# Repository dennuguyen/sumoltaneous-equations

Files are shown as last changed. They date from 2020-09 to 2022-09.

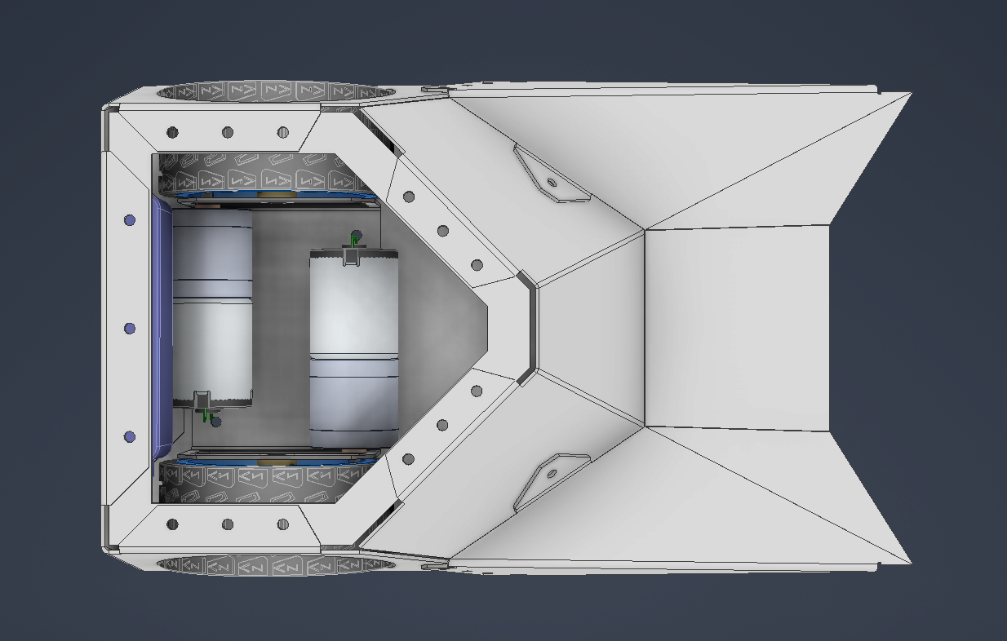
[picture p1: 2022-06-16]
sumoltaneous-equations-inventor-sheet-metal/Assembly top.png

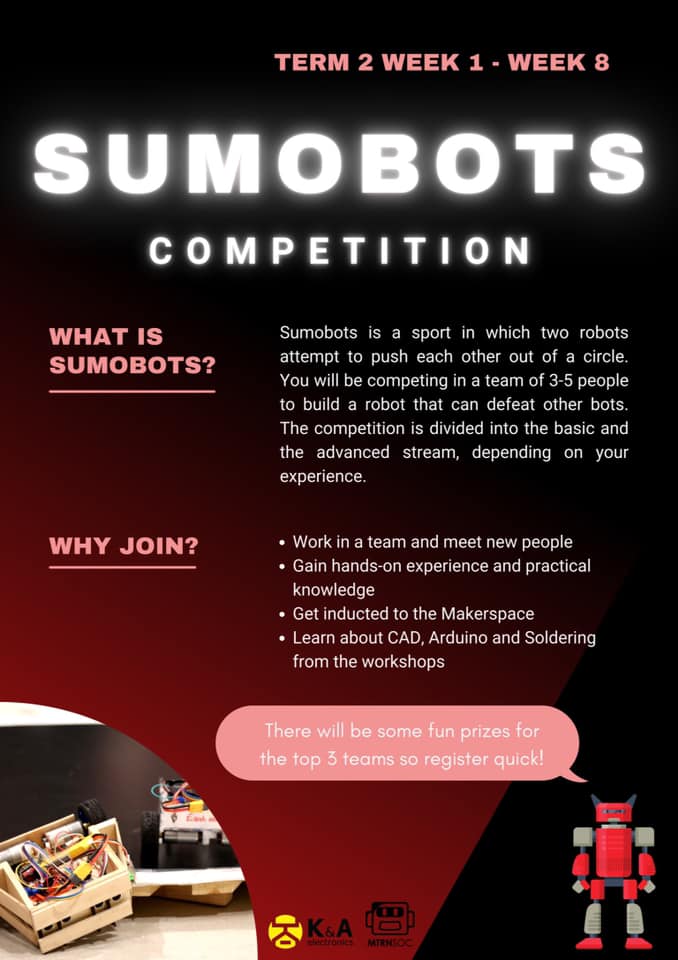
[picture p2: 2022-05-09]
README/sumobots.jpg

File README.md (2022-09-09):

# Sumoltaneous Equations
atement

Build a UGV to win the sumobot competition i.e. to win, it must be the last robot to overstep the boundary of the dohyo. It must also adhere to the rules and use the parts provided by UNSW Create.

## Resources

- Japanese Sumobots Documentary: https://youtu.be/mS-L2fpV1Is
- Sumobot Strategies: https://youtu.be/rthMiqFCiBA
- SENAI-SC Sumo Robot Example: https://blog.jsumo.com/senai-sc-sumo-robot/.
- Impala Sumo Robot Example: https://blog.jsumo.com/impala-sumo-robot/.
- Arduino Nano Datasheet: https://Datasheet.arduino.cc/hardware/nano
- Arduino Nano Pinout: https://www.makerguides.com/wp-content/uploads/2020/10/arduino-nano-pinout.png
- L298N Motor Controller Datasheet: https://components101.com/sites/default/files/component_datasheet/L298N-Motor-Driver-Datasheet.pdf
- HC-SR04 Ultrasonic Sensor Datasheet: https://www.digikey.com/htmldatasheets/production/1979760/0/0/1/hc-sr04.html
- MH-B IR Sensor Datasheet: https://components101.com/sites/default/files/component_datasheet/Datasheet%20of%20IR%20%20Sensor.pdf
- Turnigy 1250 mAh 3S 30C LiPo Battery: https://hobbyking.com/en_us/turnigy-1250mah-3s-30c-lipo-pack-long.html
- JGA25-370 DC Motor: https://www.aliexpress.com/item/1005001279982165.html
- JGA25-370 Bracket: https://www.alibaba.com/product-detail/JGA25-370-Fixed-Support-Gear-Motor_1600120808634.html
- Wheel: https://www.aliexpress.com/item/32870820813.html
- TCRT5000: https://www.vishay.com/docs/83760/tcrt5000.pdf

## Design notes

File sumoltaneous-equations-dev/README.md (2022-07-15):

# Sumoltaneous Equations

## State Diagram

```mermaid
stateDiagram-v2
    state if <<choice>>
    [*] --> if

    if --> PlanEdgeAvoidance: Edge detected
    if --> PlanAttack: Opponent detected
    if --> PlanSearch: Opponent not detected

    state PlanSearch {
        [*] --> SearchTurnRight
        SearchTurnRight: Send turn right command
        SearchTurnRight --> [*]
    }

    state PlanAttack {
        state if_which_distance_sensor <<choice>>
        state join_attack_move <<join>>
        [*] --> if_which_distance_sensor
        if_which_distance_sensor --> TurnLeft: If left distance sensor is triggered
        TurnLeft: Send turn left command
        if_which_distance_sensor --> Forward: If front distance sensor is triggered
        Forward: Send forward command
        if_which_distance_sensor --> TurnRight: If right distance sensor is triggered
        TurnRight: Send turn right command
        TurnLeft --> join_attack_move
        Forward --> join_attack_move
        TurnRight --> join_attack_move
        join_attack_move --> [*]
    }

    state PlanEdgeAvoidance {
        [*] --> AvoidTurnLeft
        AvoidTurnLeft: Send turn left command
        AvoidTurnLeft --> [*]
    }

    PlanSearch --> Move: Send move command
    PlanAttack --> Move: Send move command
    PlanEdgeAvoidance --> Move: Send move command

    state Move {
        state join_after_move <<join>>
        [*] --> DriveModel
        DriveModel
        DriveModel --> LeftMotor: Send motor command
        DriveModel --> RightMotor: Send motor command
        LeftMotor --> join_after_move
        RightMotor --> join_after_move
        join_after_move --> [*]
    }

    Move --> if
```

Move refers to moving the motors at max velocity. There are 3 moves that we can make:
- Turning left.
- Turning right.
- Moving forward.

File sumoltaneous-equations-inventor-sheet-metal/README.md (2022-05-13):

# Sumoltaneous Equations

## Autodesk Inventor Professional 2023

1. Go to https://www.autodesk.com/education/edu-software.
1. Install Autodesk Inventor Professional 2023.

You will need to provide Autodesk proof that you are a student.

## BOM

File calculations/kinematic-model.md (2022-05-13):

# Kinematic Model

kinematic-model

The sumobot's state-space representation will let us localise the robot.

Let the state vector be:
$$
\vec{x}(t) = \left(\begin{matrix} x(t) \\ y(t) \\ \phi(t) \end{matrix}\right)
$$

The change in state over time is:
$$
\frac{d\vec{x}(t)}{dt} = \frac{d}{dt}\left(\begin{matrix} x(t) \\ y(t) \\ \phi(t) \end{matrix} \right)=
    \left(
        \begin{matrix}
            v(t) \cdot \cos\left(\phi(t)\right) \\
            v(t) \cdot \sin\left(\phi(t)\right) \\
            \omega(t) \\
        \end{matrix}
    \right)
$$

- $v$ is the linear velocity in x-y directions.
- $w$ is the angular velocity.

Let the input vector be:
$$
\vec{u}(t) = \left(\begin{matrix} \omega_{L}(t) \\ \omega_{R}(t) \end{matrix}\right)
$$

- $w_{L}$ is the angular veocity for each left wheel.
- $w_{R}$ is the angular veocity for each right wheel.

The left wheels are driven by a single left motor. The right wheels are driven by a single right motor. The kinematic model can be simplified to be a two-wheeled differential where the instantaneous centre of rotation is along the centre-line between the front and rear axes.

The linear velocity is:
$$
v(t) = \frac{R_{wheel}}{2}\left(\omega_{L}(t) + \omega_{R}(t)\right)
$$

The angular velocity is:
$$
\omega(t) = \frac{R_{wheel}}{2L}\left(\omega_{R}(t) - \omega_{L}(t) \right)
$$

The change in states over time is therefore:
$$
\frac{d\vec{x}(t)}{dt} =
    \left(
        \begin{matrix}
            \frac{R_{wheel}}{2}\left(\omega_{L}(t) + \omega_{R}(t)\right) \cdot \cos\left(\phi(t)\right) \\
            \frac{R_{wheel}}{2}\left(\omega_{L}(t) + \omega_{R}(t)\right) \cdot \sin\left(\phi(t)\right) \\
            \frac{R_{wheel}}{2L}\left(\omega_{R}(t) - \omega_{L}(t) \right) \\
        \end{matrix}
    \right)
$$

> Very important to recognise that the frame of reference is the centroid of the four wheels.

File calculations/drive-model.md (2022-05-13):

# Drive Model

## Motor

The motor model is [JGA25-370](https://ae01.alicdn.com/kf/H8264bb5cf6ff431a86f8ef713a801273X.jpg) rated at $6$ V and with a $46$ reduction ratio.

At no load, the motor is rated as:
$$
\begin{aligned}
    \omega_{\text{no load}} &= 130 \text{ RPM} \\
    i_{\text{no load}} &= 0.1 \text{ A}
\end{aligned}
$$

At load, the motor is rated as:
$$
\begin{aligned}
    \tau_{\text{load}} &= 100 \text{ kg/m} \\
    \omega_{\text{load}} &= 100 \text{ RPM} \\
    i_{\text{load}} &= 0.45 \text{ A}
\end{aligned}
$$

At stall, the motor is rated as:
$$
\begin{aligned}
    \tau_{\text{stall}} &= 360 \text{ kg/m} \\
    i_{\text{stall}} &= 1.8 \text{ A}
\end{aligned}
$$

> There is no need to calculate the motor constant because the motor is given to us.

## Gear Train

gear-train

The gear ratio formula between the in and out gear is:
$$
\frac{\omega_{in}}{\omega_{out}} = \frac{n_{in}}{n_{out}} = \frac{d_{out}}{d_{in}} = \frac{\tau_{out}}{\tau_{in}}
$$

Given the dimensional constraints of the gears:
$$
\begin{aligned}
    d_{out} &= 60 \text{ mm} \\
    d_{in} &= 15 \text{ mm} \\
\end{aligned}
$$

With an input torque of $100$ kg/m, the output torque is:
$$
\begin{aligned}
    \frac{d_{out}}{d_{in}} &= \frac{\tau_{out}}{\tau_{in}} \\
    \frac{60}{15} &= \frac{\tau_{out}}{100} \\
    \therefore \tau_{out} &= 400 \text{ kg/m}
\end{aligned}
$$

## Control System

A control system is required to control the torque output of the motor. This is done through observing the supplied current.

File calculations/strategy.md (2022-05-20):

# Strategy

## Mapping

The map is a dohyo i.e. a ring with a black background and white edges.

We know the map will always be sparse. So sparse that it may not be worth the effort to even map it. We just have to make sure we don't risk reaching the edge of the dohyo.

We should only care about where the edge of the ring is and where we are relative to that (this should save A LOT of computation power). How do we do this?

We know:
- The diameter of the ring.
- Our starting position.

If we reach the edge of the dohyo, we can reset our state vector to be at some random point on the edge of the dohyo.

When we track our position, it will be some float coordinates.

## Search Patterns

When searching for the opponent, there are multiple patterns which can be employed:

### Radar

The sumobot just spins on the spot and searches for the opponent.

### Random Search

The sumobot randomly moves to a point on the dohyo and will end its search pattern when it identifies an opponent.

## Path Planning

We know:
- The diameter of the ring.
- Our position within the ring.
- And maybe our opponent's position within the ring too.

This is all the information we need to perform path planning.

There are a few path planning strategies:

### Search And Push (SAP)

An extremely simple strategy.

```mermaid
flowchart LR
    search[Search for Opponent] -->|If target acquired| push[Push Opponent]
    push -->|If lost target| search
```

### Search And Push* (SAP*)

An improved strategy on SAP which considers localisation.

```mermaid
flowchart LR
    search[Search for Opponent] -->|If target acquired| localise_opp[Localise Opponent]
    localise_opp --> plan_path[Plan Path]
    plan_path --> push[Execute Path Step] -->|To update data| search
```

The path planning can be complex e.g.
- We may only want to push the opponent from the inside of the sumobot.
- We may only want to push the opponent from its side or behind and not head on.

The path planning algorithm could be implemented with:
- Queuing waypoints.

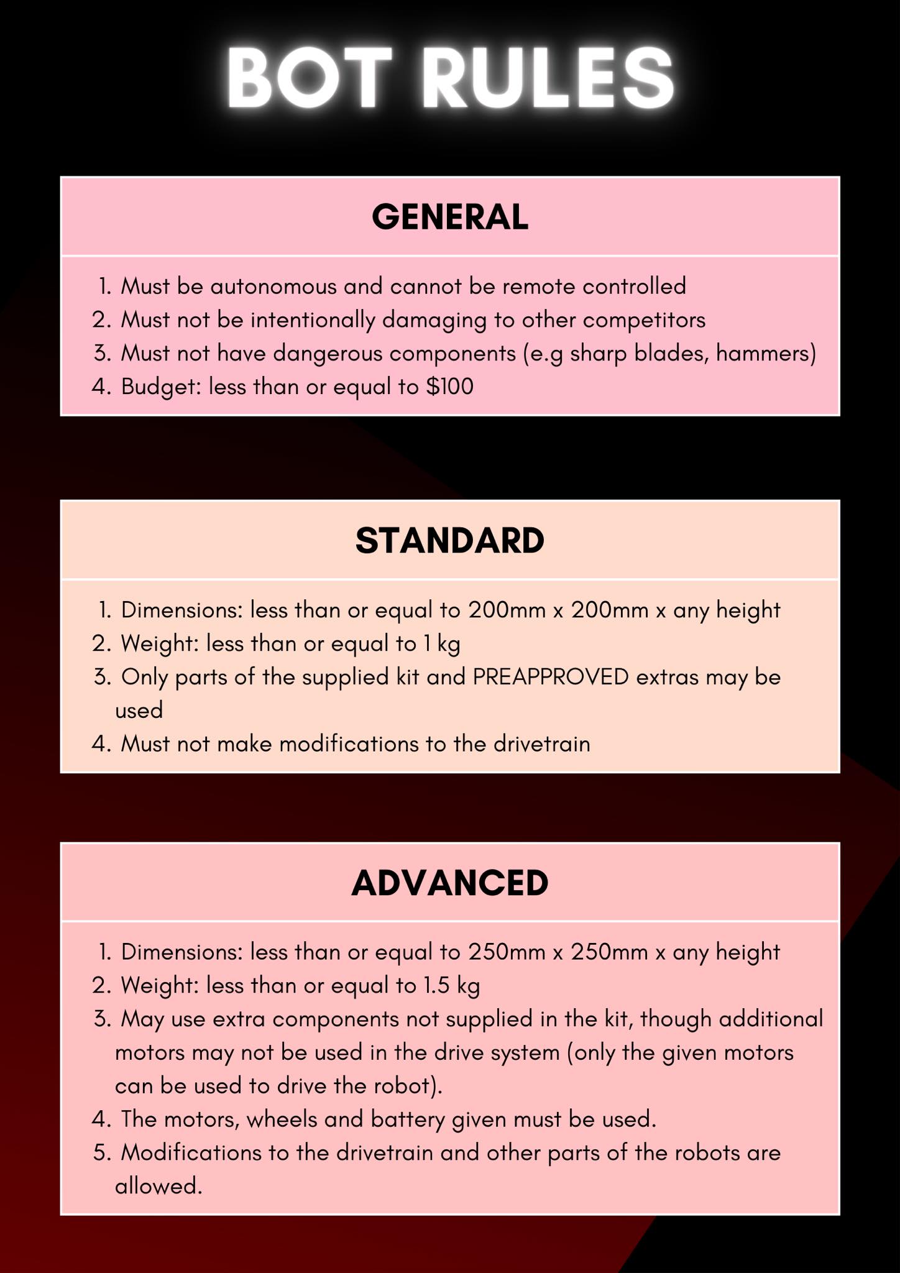
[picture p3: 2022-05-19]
README/bot-rules.jpg

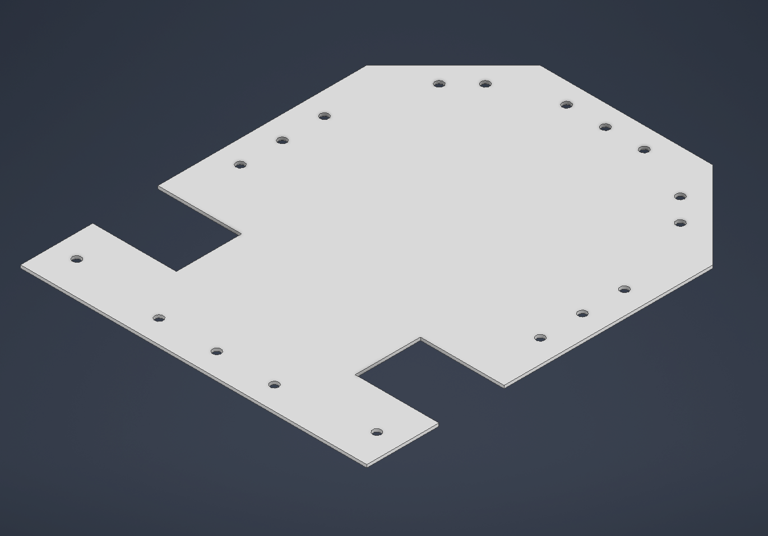
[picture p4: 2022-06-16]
sumoltaneous-equations-inventor-sheet-metal/Bottom.png

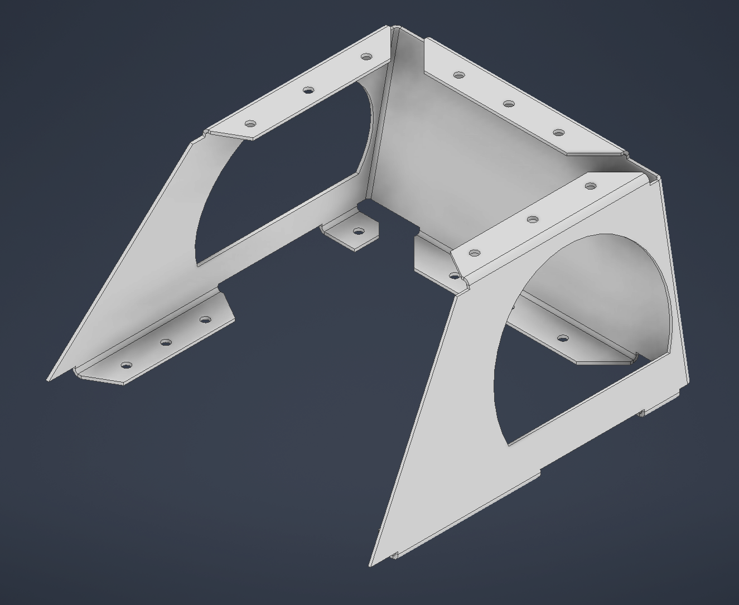
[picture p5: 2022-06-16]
sumoltaneous-equations-inventor-sheet-metal/Back.png

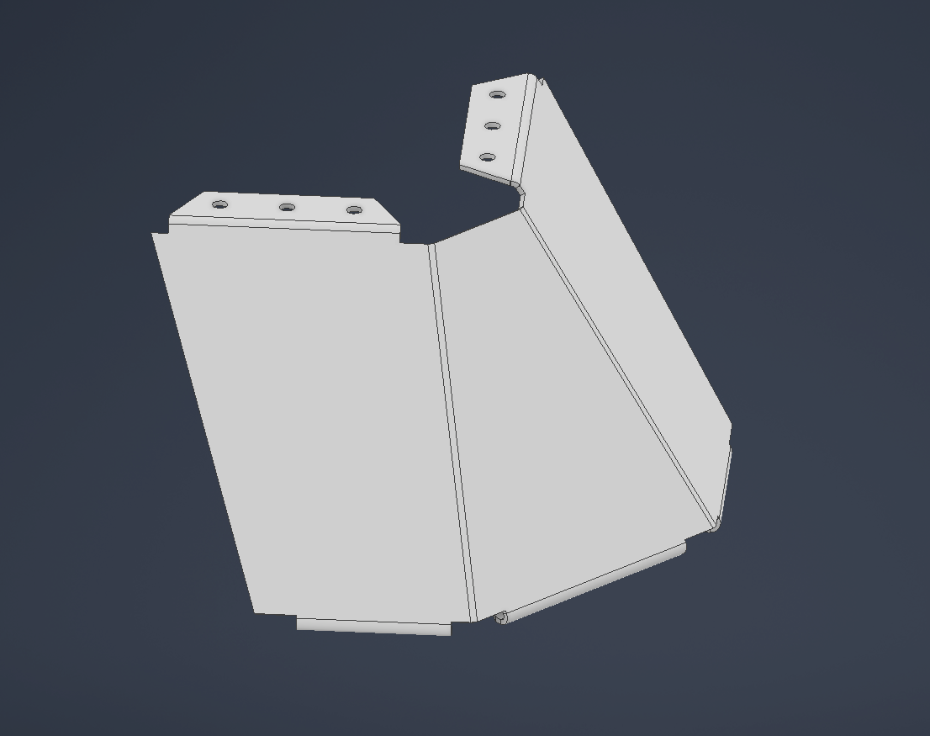
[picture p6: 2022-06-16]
sumoltaneous-equations-inventor-sheet-metal/Front.png

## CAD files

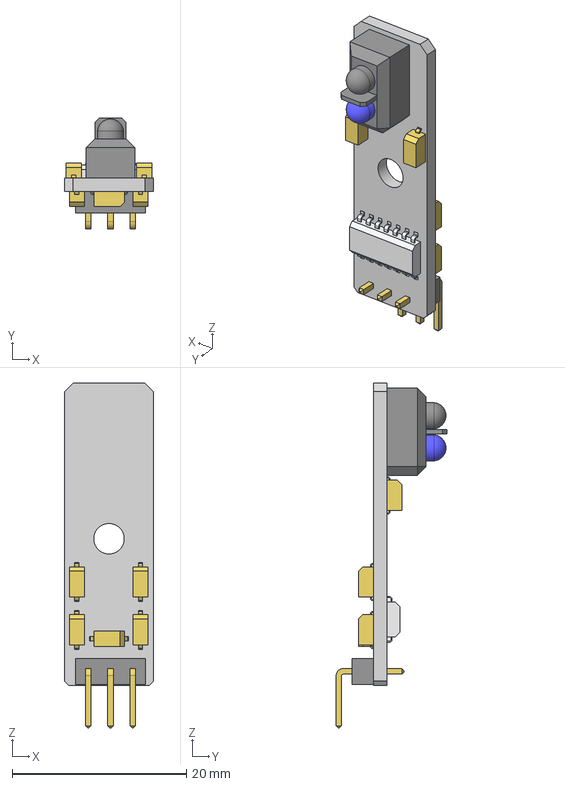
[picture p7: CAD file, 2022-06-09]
sumoltaneous-equations-inventor-sheet-metal/TCRT5000.step
10.2 x 12.7 x 39.6 mm
Line Sensor_1
TCR5000
14 Pin SMT
3 Pin Header 90 Degree line
Cap1 SMT x 7

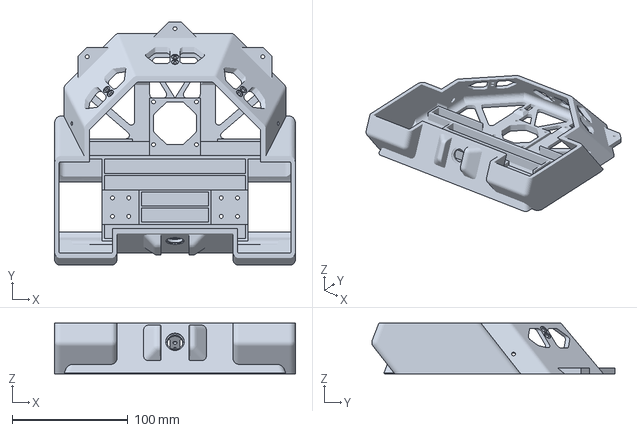
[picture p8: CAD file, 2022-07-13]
sumoltaneous-equations-inventor/v3.3mf
208.0 x 210.1 x 44.0 mm

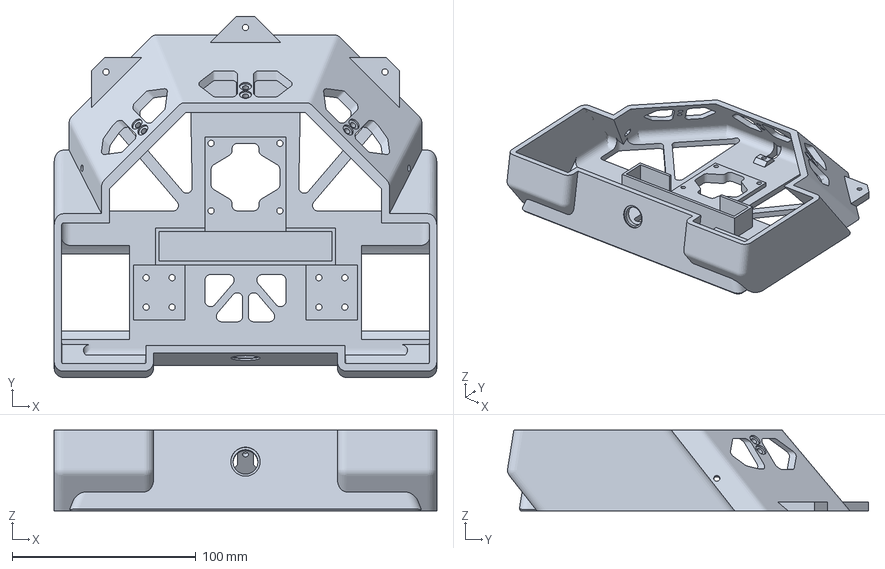
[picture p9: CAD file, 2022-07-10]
sumoltaneous-equations-inventor/AI3MSPRO_Body.3mf
208.0 x 196.2 x 44.0 mm

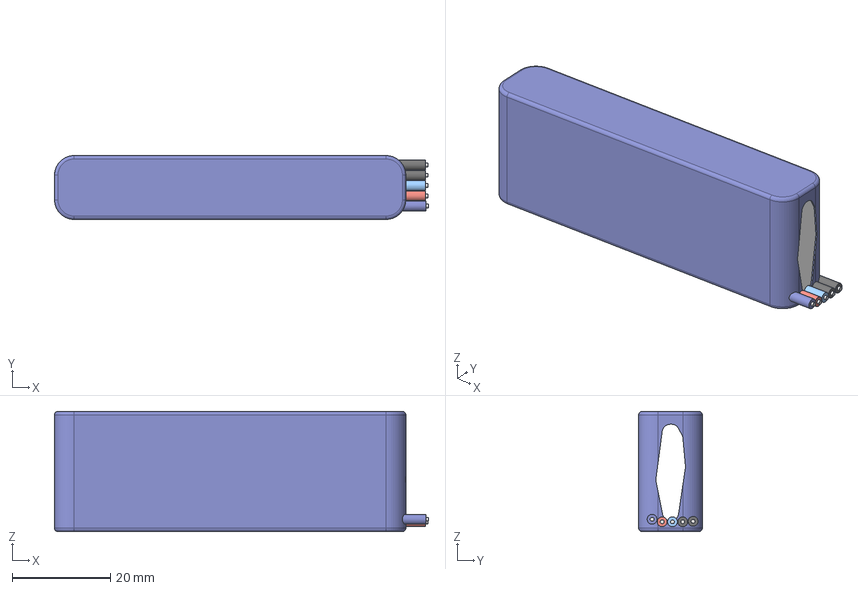
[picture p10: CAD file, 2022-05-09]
sumoltaneous-equations-inventor-sheet-metal/turnigy-lipo-battery.step
76.2 x 13.0 x 24.5 mm

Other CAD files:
sumoltaneous-equations-inventor-sheet-metal/spur-gear-1m-15t.step
sumoltaneous-equations-inventor/v2.3mf
sumoltaneous-equations-inventor-sheet-metal/Backp.ipt
sumoltaneous-equations-inventor-sheet-metal/Bottomp.ipt
sumoltaneous-equations-inventor-sheet-metal/Frontp.ipt
sumoltaneous-equations-inventor-sheet-metal/JGA25-370-bracket-standoff.ipt
sumoltaneous-equations-inventor-sheet-metal/JGA25-370-bracket.ipt
sumoltaneous-equations-inventor-sheet-metal/JGA25-370.ipt
sumoltaneous-equations-inventor-sheet-metal/Motor-bracket.ipt
sumoltaneous-equations-inventor-sheet-metal/Motor-mountp.ipt
sumoltaneous-equations-inventor-sheet-metal/Rampp.ipt
sumoltaneous-equations-inventor-sheet-metal/Spacer.ipt
sumoltaneous-equations-inventor-sheet-metal/Topp.ipt
sumoltaneous-equations-inventor-sheet-metal/body-shape.ipt
sumoltaneous-equations-inventor-sheet-metal/hc-sr04-bracket.ipt
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

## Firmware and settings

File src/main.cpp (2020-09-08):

#include <Arduino.h>

struct Pin {
   public:
    Pin(int pno) : pno(pno), val(LOW) {}

   public:
    int pno;  // pin number
    int val;  // pin value
};

class Wheel {
   public:
    Wheel(int in1, int in2) : in1(Pin(in1)), in2(Pin(in2)) {}
    void init(void) {
        pinMode(in1.pno, OUTPUT);
        pinMode(in2.pno, OUTPUT);
    }
    void forward(void) {
        in1.val = HIGH;
        in2.val = LOW;
    }
    void backward(void) {
        in1.val = LOW;
        in2.val = HIGH;
    }
    void brake(void) {
        in1.val = LOW;
        in2.val = LOW;
    }

   public:
    Pin in1;
    Pin in2;
};

class Sonar {
   public:
    Sonar(int echo, int trig) : echo(echo), trig(trig) {}
    void init(void) {
        pinMode(echo.pno, INPUT);
        pinMode(trig.pno, OUTPUT);
    }
    void clear(void) {
        digitalWrite(trig.pno, LOW);
    }
    void send(void) {
        digitalWrite(trig.pno, HIGH);
    }
    double receive(void) {
        return pulseIn(echo.pno, HIGH) * 0.034 / 2;  // distance in cm
    }

   public:
    Pin echo;
    Pin trig;
};

class Infrared {
   private:
    enum colours {
        MIN = 0,
        BLACK = 900,
        MAX = 1023,
    };

   public:
    Infrared(int sig) : sig(sig) {}
    void init(void) {
        pinMode(sig.pno, INPUT);
    }
    bool edge(void) {
        return analogRead(sig.pno) > BLACK;
    }

   private:
    Pin sig;
};

class Bot {
   private:
    enum wheels {
        LF,  // left front
        RF,  // right front
        LB,  // left back
        RB,  // right back
    };
    enum sensors {
        FRONT,
        LEFT,
        RIGHT,
        BACK,
    };

   public:
    Bot(Wheel (&wheel)[4], Infrared (&gnd)[4], Sonar (&opp)[4])
        : wheel(wheel), gnd(gnd), opp(opp) { init(); }
    void init(void) {
        for (int i = 0; i < 4; i++) {
            wheel[i].init();
            gnd[i].init();
            opp[i].init();
        }
    }
    void forward(void) {
        wheel[LF].forward();
        wheel[RF].forward();
        wheel[LB].forward();
        wheel[RB].forward();
    }
    void backward(void) {
        wheel[LF].backward();
        wheel[RF].backward();
        wheel[LB].backward();
        wheel[RB].backward();
    }
    void brake(void) {
        wheel[LF].brake();
        wheel[RF].brake();
        wheel[LB].brake();
        wheel[RB].brake();
    }
    void left(void) {
        wheel[LF].backward();
        wheel[RF].forward();
        wheel[LB].backward();
        wheel[RB].forward();
    }
    void right(void) {
        wheel[LF].forward();
        wheel[RF].backward();
        wheel[LB].forward();
        wheel[RB].backward();
    }
    void write(void) {
        for (int i = 0; i < 4; i++) {
            digitalWrite(wheel[i].in1.pno, wheel[i].in1.val);
            digitalWrite(wheel[i].in2.pno, wheel[i].in2.val);
        }
    }

   private:
    Wheel (&wheel)[4];
    Infrared (&gnd)[4];  // Infrared sensor detects boundary
    Sonar (&opp)[4];     // Sonar detects opponent
};

int main(void) {
    Wheel wheel[4] = {Wheel(PD0, PD1), Wheel(PD2, PD3), Wheel(PD4, PD5), Wheel(PD6, PD7)};
    Infrared gnd[4] = {Infrared(A0), Infrared(A1), Infrared(A2), Infrared(A3)};
    Sonar opp[4] = {Sonar(PD1, PD2), Sonar(PD1, PD2), Sonar(PD3, PD4), Sonar(PD5, PD6)};
    Bot b(wheel, gnd, opp);

    Serial.begin(9600);

    while (1) {
        // Check edges
        for (int i = 0; i < 4; i++)
            ;

        // Write-out pins.
        b.write();
        delay(50);
    }

    return EXIT_SUCCESS;
}

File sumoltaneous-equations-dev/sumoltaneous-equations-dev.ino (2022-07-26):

#include <Arduino.h>

#include "DistanceSensor.hpp"
#include "Drive.hpp"
#include "EdgeAvoidance.hpp"
#include "IRSensor.hpp"
#include "Motor.hpp"
#include "ToggleButton.hpp"

Motor left_motor(10, A2, A3);
Motor right_motor(11, A0, A1);
Drive drive_model(left_motor, right_motor, 65, 160);

DistanceSensor left_distance_sensor(2, 3);
DistanceSensor front_distance_sensor(4, 5);
DistanceSensor right_distance_sensor(7, 6);

IRSensor left_ir_sensor(8);
// IRSensor right_ir_sensor(9);
// EdgeAvoidance edge_avoidance(left_ir_sensor, right_ir_sensor);

ToggleButton button(12);

void setup() {
    Serial.begin(9600);
    button.await(true);
    delay(5000);
}

void loop() {
    if (left_ir_sensor.read()) {
        drive_model.reverse();
        delay(200);
    } else if (front_distance_sensor.echo() < 800) {
        drive_model.forward();
    } else if (left_distance_sensor.echo() < 800) {
        drive_model.turn_left();
    } else if (right_distance_sensor.echo() < 800) {
        drive_model.turn_right();
    } else {
        drive_model.turn_left();
    }

    if (button.read() == false) {
        drive_model.stop();
        button.await(true);
        delay(5000);
    }
}

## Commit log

2020-09-07 Add getting battery requirement step
2020-09-08 Add sensor classes
2020-09-08 Clarify enum wheels
2020-09-09 Perform motor-battery calculations
2020-09-09 Perform some basic torque calculation
2020-09-09 Ask motor driver questions
2020-12-04 Reorganise directory
    [ARDUINO NANO.SLDPRT, BALLAST.SLDPRT, CHASSIS.3MF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]
2022-04-30 Update power supply in WBS.
2022-04-30 Restructure repository.
    [ARDUINO NANO.SLDPRT, BALLAST.SLDPRT, CHASSIS.3MF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]
2022-05-09 Add battery spec.
2022-05-09 Rename IR sensor.
2022-05-09 Source COTS.
    [ARDUINO NANO.SLDPRT, BALLAST.SLDPRT, CHASSIS.3MF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]
2022-05-09 Find motor model.
2022-05-09 Find wheel.
2022-05-09 Create sheet metal concept.
    [floor.ipt, ramp.ipt]
2022-05-09 Create pyramid for sheet metal concept.
    [chassis.ipt, floor.ipt, ramp.ipt]
2022-05-09 Finalise sheet metal concept.
    [chassis.ipt, ramp.ipt, side.ipt]
2022-05-09 Rename side to panel. Import wheel and motor.
    [JGA25-370.ipt, JGA25-370.step, chassis.ipt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]
2022-05-10 Add motor bracket.
    [JGA25-370-bracket.ipt, JGA25-370-bracket.step]
2022-05-10 Create wheel subasm.
    [JGA25-370-bracket.ipt, ramp.ipt]
2022-05-10 Put wheel subasm in chassis.
    [JGA25-370-bracket-standoff.ipt, chassis.ipt]
2022-05-13 Prep kinematic model.
2022-05-13 Do gear train calcs.
    [gear-train-sketch.ipt]
2022-05-13 Update gear dimensions.
    [gear-train-sketch.ipt]
2022-05-13 Design motor cage.
    [chassis.ipt, motor-cage.ipt]
2022-05-13 Draw kinematic model diagram.
    [motor-cage.ipt]
2022-05-13 Add BOM section.
2022-05-13 Iterate on motor cage.
    [motor-cage.ipt]
2022-05-13 Mate motors with motor cage.
2022-05-14 Draft gear train.
    [JGA25-370-bracket.step, JGA25-370.step, chassis.ipt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]
2022-05-16 Add IMU.
2022-05-17 Initial commit.
    [sumoltaneous_equations.kicad_pcb, sumoltaneous_equations.kicad_sch]
2022-05-19 Sketch HC-SR04 placement.
    [hc-sr04-sensor-placement-sketch.ipt]
2022-05-19 Create ultrasonic sensor mount.
    [chassis.ipt, hc-sr04-bracket.ipt, panel.ipt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]
2022-05-30 final body shape
    [Backp.ipt, Bottomp.ipt, Final-ass.iam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]
2022-05-31 Ramp done
    [Backp.ipt, Bottomp.ipt, Final-ass.iam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]
2022-06-01 Fixed parametric definitions
    [body-shape.ipt]
2022-06-02 Final alignment
    [Backp.ipt, Bottomp.ipt, Final-ass.iam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]
2022-06-03 Added motor mount
    [Backp.ipt, Bottomp.ipt, Final-ass.iam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]
2022-06-03 Fixed assembly
    [Backp.ipt, Bottomp.ipt, Frontp.ipt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]
2022-06-06 Added ultrasonic sensor windows
    [body-shape.ipt]
2022-06-09 Update sensor model.
    [MH-B-ir-sensor.step, TCRT5000.step]
2022-06-16 Final assembly (hopefully)
    [Backp.ipt, Bottomp.ipt, Frontp.ipt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]
2022-06-16 Add mounting hole for L298N.
    [body-shape.ipt]
2022-06-22 Move old revision.
    [Backp.ipt, Bottomp.ipt, Frontp.ipt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]
2022-06-22 Hollow chassis
    [chassis.ipt]
2022-06-22 Hollow chassis with FEA
    [chassis.ipt]
2022-06-22 Add mounting hole for JGA25-370.
    [chassis.ipt]
2022-06-23 Get bracket from old version.
    [JGA25-370-bracket.ipt, JGA25-370-mount.ipt]
2022-06-23 making ramp mounts
    [chassis.ipt]
2022-06-23 Add COTS and create wheel sub asm.
    [JGA25-370.ipt, TCRT5000.step, turnigy-lipo-battery.step]
2022-06-23 Finalise motor mounting hole sketch.
    [chassis.ipt]
2022-06-23 Add wheel sub asm to main asm.
    [sumoltaneous-equations.iam]
2022-06-23 made the ramp and fixed wheel clearances, need to finalise mounting holes
    [chassis.ipt, sumoltaneous-equations.iam]
2022-06-23 Add an example chassis.
    [example-chassis.ipt]
2022-06-24 Removed fillets temporatialy and added mounting points for motor and motor controller
    [chassis.ipt]
2022-06-24 Just need ir and ultrasonic sensor mounts
    [chassis.ipt]
2022-06-24 forgot to add the assembly
2022-06-24 Modify HC-SR04 bracket to have captive nuts.
    [hc-sr04-bracket.ipt]
2022-06-24 Tweaked angles
    [chassis.ipt]
2022-06-24 Increase distance between bolts.
    [hc-sr04-bracket.ipt]
2022-06-26 fixed US mount and made it a spider
    [chassis.ipt, hc-sr04-bracket.ipt]
2022-06-26 Write motor abstraction.
2022-06-26 Document Motor class.
2022-06-26 First final version
    [chassis.ipt, hc-sr04-bracket.ipt]
2022-06-26 Added lightness
    [chassis.ipt]
2022-06-26 First print
    [chassis.ipt]
2022-06-29 Add IR sensor resource.
2022-06-29 Write IR sensor interface.
2022-06-29 Specify pin outs.
2022-06-29 Remove kicad folder.
    [sumoltaneous_equations.kicad_pcb, sumoltaneous_equations.kicad_sch]
2022-06-29 Write kinematic model.
2022-07-09 Chassis v2 nearly done
    [AI3MSPRO_Body.3mf, JGA25-370-bracket.ipt, chassis.ipt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]
2022-07-10 Body done
    [chassis.ipt, v2.3mf]
2022-07-10 Make read_pin interruptable.
2022-07-10 Remove read() as it is not needed due to interrupt.
2022-07-10 Clean style. Use ternary to handle no detection case.
2022-07-12 Final chassis
    [JGA25-370-bracket.ipt, chassis.ipt, v3.3mf]
2022-07-14 Implement IR sensor behaviour.
2022-07-14 Add threshold to ultrasonic sensor detection.
2022-07-15 fixed motor mounts
    [hc-sr04-bracket.ipt]
2022-07-18 Implement public set method for Motor.
2022-07-18 Clean up use of Motor and Drive class.
